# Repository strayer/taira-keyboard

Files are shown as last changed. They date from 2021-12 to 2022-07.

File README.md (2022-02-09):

# Taira Keyboard

## What?

A wireless low-profile split mechanical keyboard with 66 keys inspired by the
ErgoDash and Corne Chocolate. It runs ZMK on two nice!nanos, is fully wireless
via Bluetooth and uses Kailh Choc V1 switches in a 18x19mm grid layout.

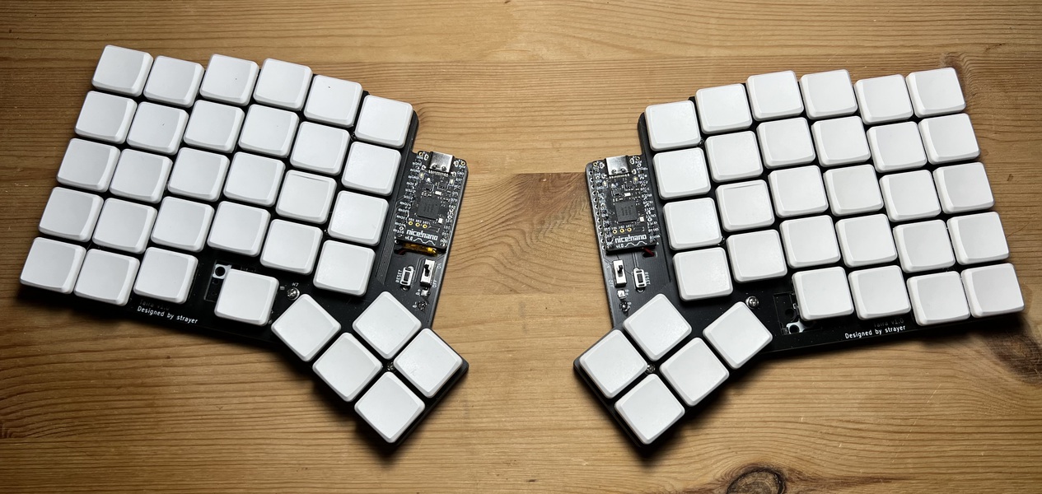
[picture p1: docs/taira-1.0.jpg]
An assembled Taira v1.0


## Why?

I used an ErgoDash with MX switches for over a year multiple hours each day.
Even though I love typing on it, it always felt too bulky and the wires really
started to annoy me - especially when moving between workplaces. At some point I
discovered ZMK and started plans on building a keyboard based on the ErgoDash,
but as low-profile as I could manage.

After investigating which other low-profile keyboards exist in the community, I
quickly realized that the most sophisticated offer seems to be the Corne
Chocolate. This keyboard is heavily based upon the footprints of the Corne
Chocolate, but layed out in a layout very similar to the original ErgoDash.

### ErgoDash comparison

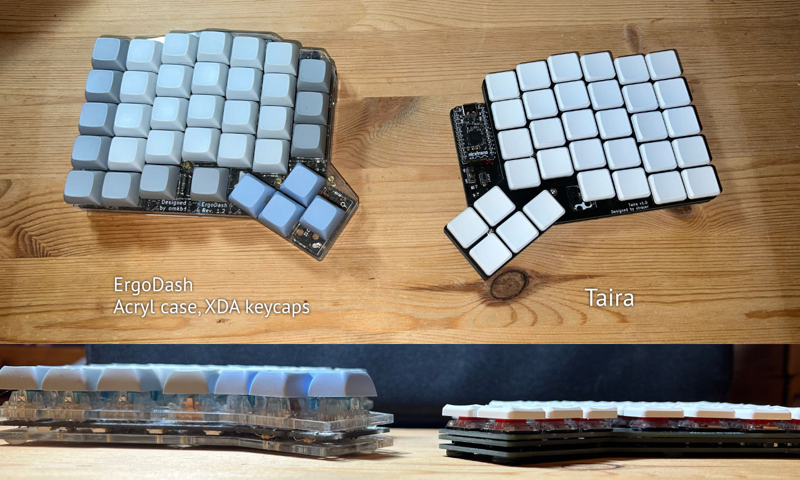
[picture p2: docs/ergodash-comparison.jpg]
An ErgoDash next to a Taira


## Build guide

Follow the [build guide](BUILDGUIDE.md) if you are interested in building your
own Taira.

## Firmware

The ZMK firmware is managed in a separate repository: [strayer/taira-keyboard-zmk-config]

[strayer/taira-keyboard-zmk-config]: https://github.com/strayer/taira-keyboard-zmk-config

## Acknowledgements

Thanks to [@omkbd](https://github.com/omkbd) and
[@foostan](https://github.com/foostan/) for releasing both the ErgoDash and the
Corne Chocolate under the MIT license. Without their work, this keyboard would
not exist.

- https://github.com/omkbd/ErgoDash
- https://github.com/foostan/crkbd/tree/main/corne-chocolate
- an unnamed coworker who helped me _a lot_ while planning and working on the
  keyboard

## Copyright

Copyright 2022 Sven Grunewaldt

License: [MIT](LICENSE)

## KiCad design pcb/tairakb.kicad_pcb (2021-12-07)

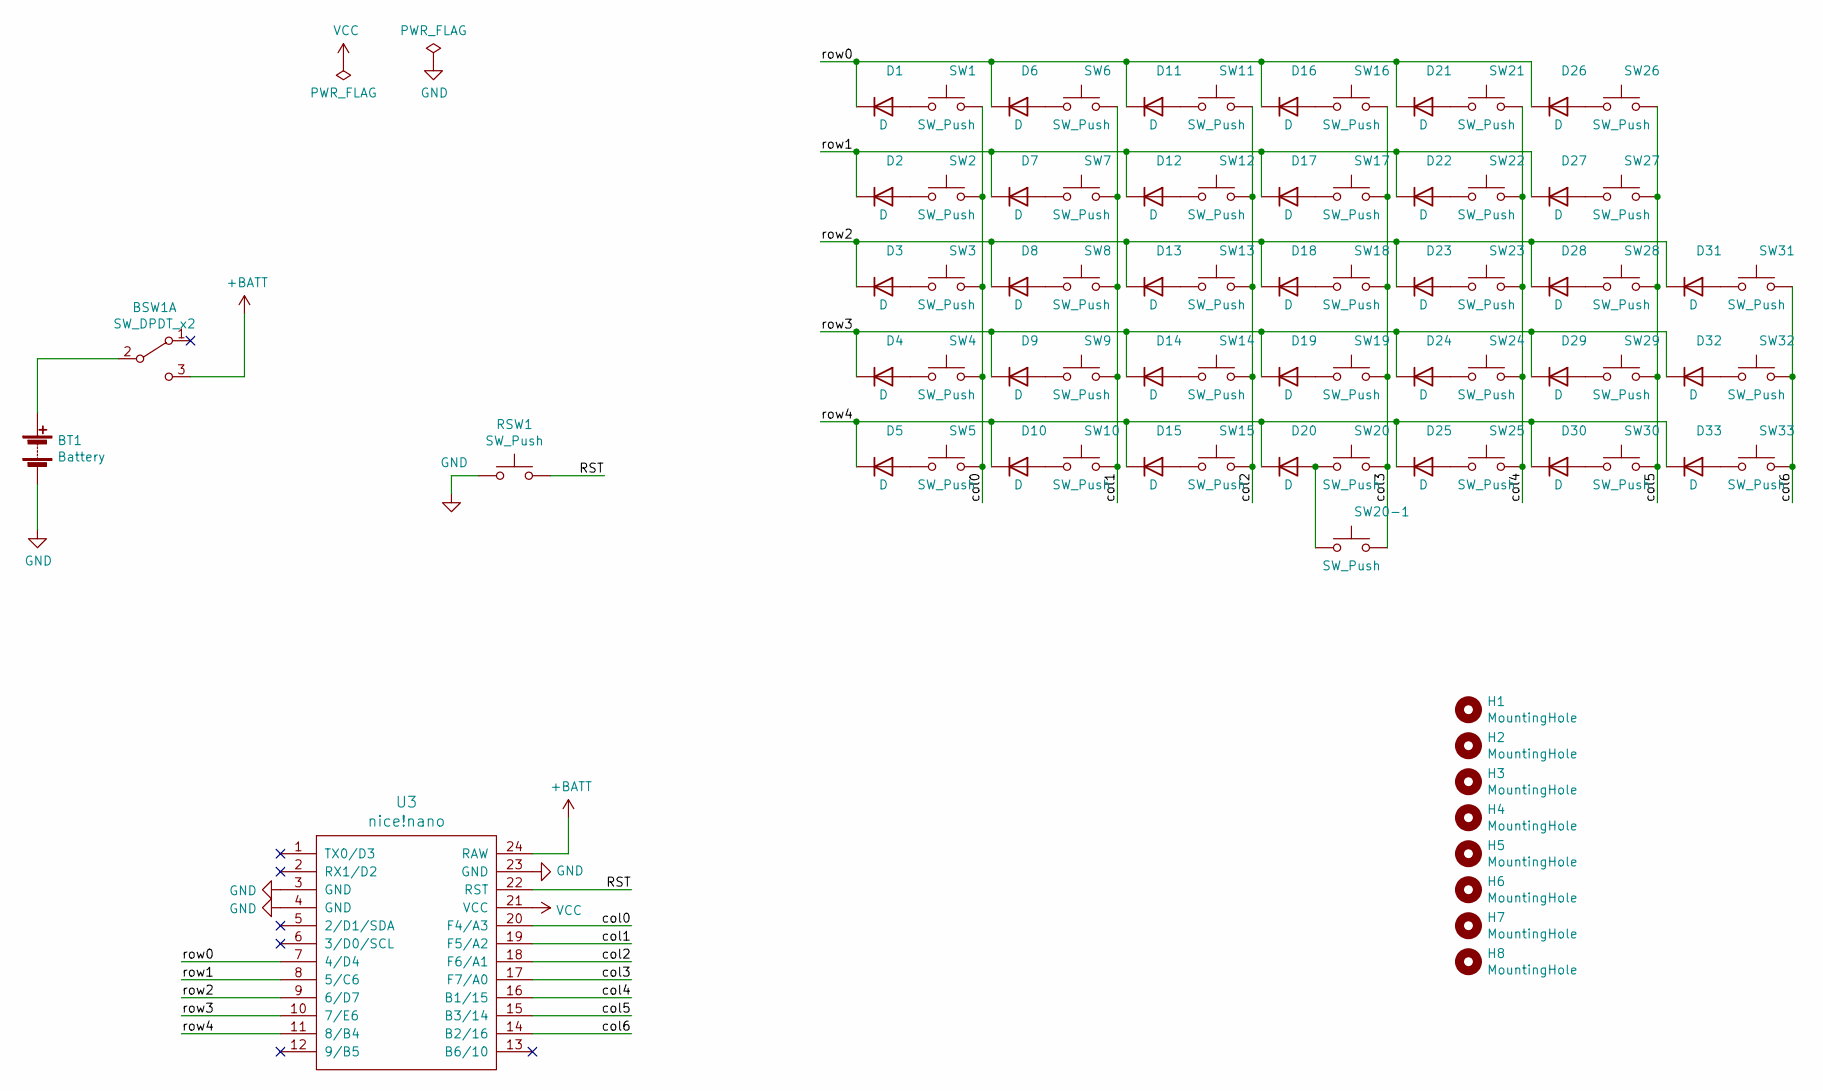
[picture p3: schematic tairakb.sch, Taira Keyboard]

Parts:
BSW1: SW_DPDT_x2; SS-12D00
BT1: Battery; Battery_Wire_Connector
D1, D2, D3, D4, D5, D6, D7, D8, D9, D10, D11, D12, D13, D14, D15, D16, D17, D18, D19, D20, D21, D22, D23, D24, D25, D26, D27, D28, D29, D30, D31, D32, D33: D; D3_SMD
H1, H2, H3, H4, H5, H6, H7, H8: MountingHole; LEGO_HOLE
RSW1: SW_Push; ResetSW
SW1, SW2, SW3, SW4, SW5, SW6, SW7, SW8, SW9, SW10, SW11, SW12, SW13, SW14, SW15, SW16, SW17, SW18, SW19, SW20, SW20-1, SW21, SW22, SW23, SW24, SW25, SW26, SW27, SW28, SW29, SW30, SW31, SW32, SW33: SW_Push; Choc_Hotswap
U3: nice!nano; nicenano

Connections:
+BATT: BSW1.3 (C), U3.24 (RAW)
/RST: RSW1.2, U3.22 (RST)
/col0: SW1.2, SW2.2, SW3.2, SW4.2, SW5.2, U3.20 (F4/A3)
/col1: SW6.2, SW7.2, SW8.2, SW9.2, SW10.2, U3.19 (F5/A2)
/col2: SW11.2, SW12.2, SW13.2, SW14.2, SW15.2, U3.18 (F6/A1)
/col3: SW16.2, SW17.2, SW18.2, SW19.2, SW20.2, SW20-1.2, U3.17 (F7/A0)
/col4: SW21.2, SW22.2, SW23.2, SW24.2, SW25.2, U3.16 (B1/15)
/col5: SW26.2, SW27.2, SW28.2, SW29.2, SW30.2, U3.15 (B3/14)
/col6: SW31.2, SW32.2, SW33.2, U3.14 (B2/16)
/row0: D1.1 (K), D6.1 (K), D11.1 (K), D16.1 (K), D21.1 (K), D26.1 (K), U3.7 (4/D4)
/row1: D2.1 (K), D7.1 (K), D12.1 (K), D17.1 (K), D22.1 (K), D27.1 (K), U3.8 (5/C6)
/row2: D3.1 (K), D8.1 (K), D13.1 (K), D18.1 (K), D23.1 (K), D28.1 (K), D31.1 (K), U3.9 (6/D7)
/row3: D4.1 (K), D9.1 (K), D14.1 (K), D19.1 (K), D24.1 (K), D29.1 (K), D32.1 (K), U3.10 (7/E6)
/row4: D5.1 (K), D10.1 (K), D15.1 (K), D20.1 (K), D25.1 (K), D30.1 (K), D33.1 (K), U3.11 (8/B4)
GND: BT1.2 (-), RSW1.1, U3.3 (GND), U3.4 (GND), U3.23 (GND)
unnamed: BSW1.2 (B), BT1.1 (+)
unnamed: D1.2 (A), SW1.1
unnamed: D2.2 (A), SW2.1
unnamed: D3.2 (A), SW3.1
unnamed: D4.2 (A), SW4.1
unnamed: D5.2 (A), SW5.1
unnamed: D6.2 (A), SW6.1
unnamed: D7.2 (A), SW7.1
unnamed: D8.2 (A), SW8.1
unnamed: D9.2 (A), SW9.1
unnamed: D10.2 (A), SW10.1
unnamed: D11.2 (A), SW11.1
unnamed: D12.2 (A), SW12.1
unnamed: D13.2 (A), SW13.1
unnamed: D14.2 (A), SW14.1
unnamed: D15.2 (A), SW15.1
unnamed: D16.2 (A), SW16.1
unnamed: D17.2 (A), SW17.1
unnamed: D18.2 (A), SW18.1
unnamed: D19.2 (A), SW19.1
unnamed: D20.2 (A), SW20.1, SW20-1.1
unnamed: D21.2 (A), SW21.1
unnamed: D22.2 (A), SW22.1
unnamed: D23.2 (A), SW23.1
unnamed: D24.2 (A), SW24.1
unnamed: D25.2 (A), SW25.1
unnamed: D26.2 (A), SW26.1
unnamed: D27.2 (A), SW27.1
unnamed: D28.2 (A), SW28.1
unnamed: D29.2 (A), SW29.1
unnamed: D30.2 (A), SW30.1
unnamed: D31.2 (A), SW31.1
unnamed: D32.2 (A), SW32.1
unnamed: D33.2 (A), SW33.1
VCC: U3.21 (VCC)

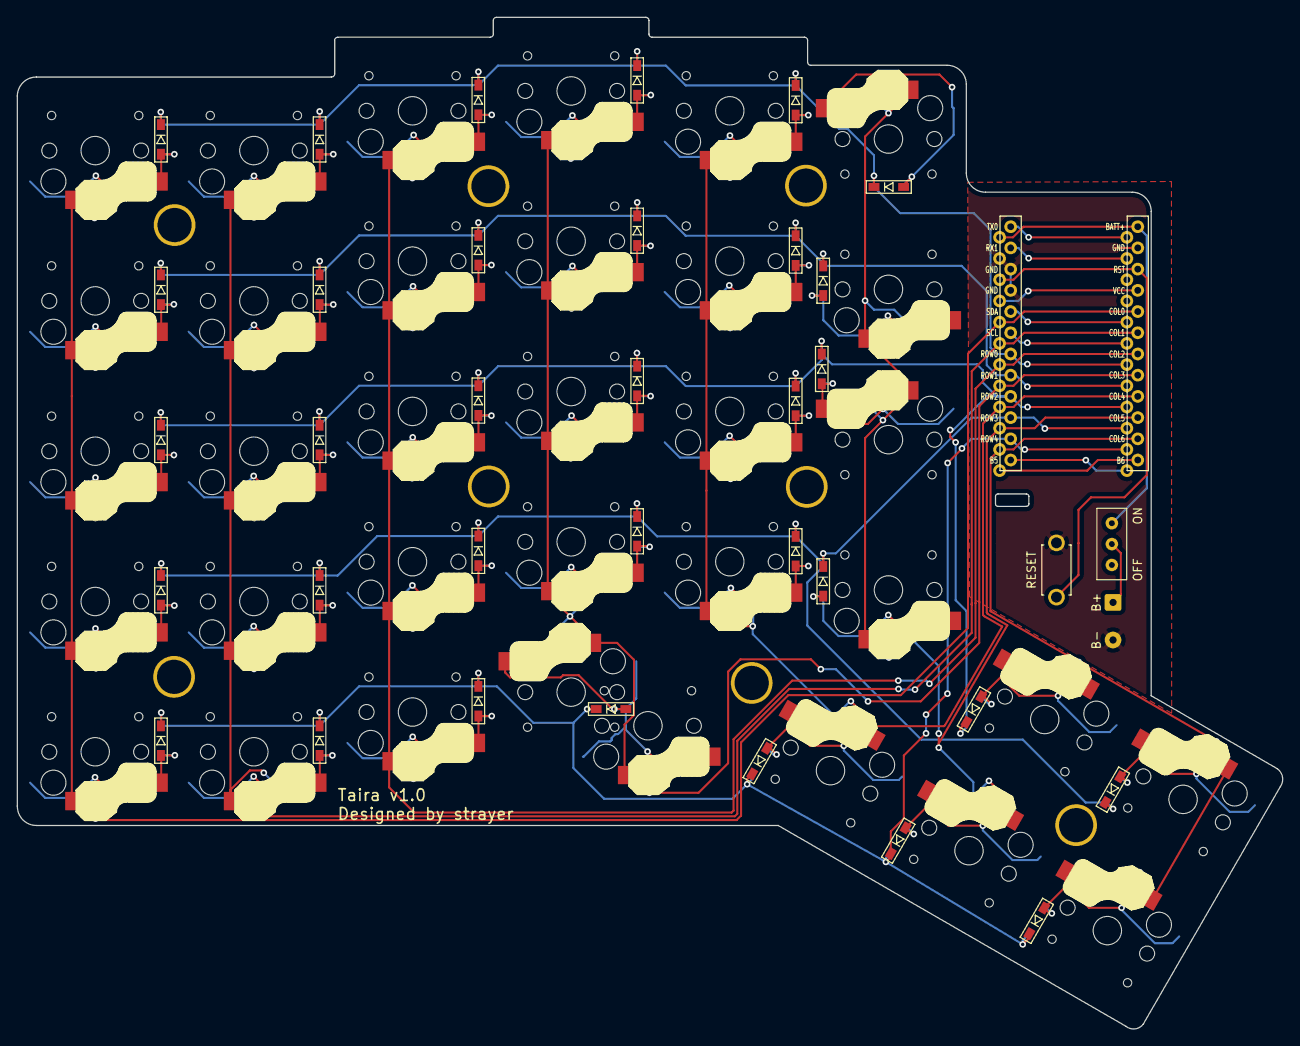
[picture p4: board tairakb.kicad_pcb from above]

Board: 2 copper layers, 151.5 x 121.2 mm, 79 parts (0 on the bottom side), 49 nets.

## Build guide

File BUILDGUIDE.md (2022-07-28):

# Build Guide

## Parts

The following parts list has links to various shops. Please don't see this as an
endorsement for the shops, its just where I ended up ordering the things I used
to help you find the correct parts. I found it quite difficult to find screws
and spacers that will fit the tight build, for example.

| Name | Amount | Remarks | Part |
| :--- | :----- | :--- | :--- |
| PCB | 2 | | |
| Top plate | 2 | | |
| Bottom plate | 2 | | |
| nice!nano | 2 | | [nice!nano on nicekeyboards.com] |
| 301230 LiPo battery | 2 | | |
| Mill-Max Series 315 header | 4 | | [headers on keycapsss.com] |
| Mill-Max Series 315 pin | 48 | | [pins on keycapsss.com] |
| Tactile switch | 2 | | [TS-1136-4.3] |
| Power switch | 2 | | [SS12D00] |
| Diode | 66 | | SOD-123FL |
| Kailh Choc Hotswap Socket  | 66 | | [Choc Type Hot Swap Socket] |
| Key switch | 66 | | PG1350, NOT Choc V2! |
| Keycaps | 66 | The Taira is NOT compatible with keycaps intended for 19x19mm switch spacing! | [MBK Choc Low Profile Blank Keycaps] |
| Spacer M2 4mm | 16 | | [brass round standoff, m2x4] |
| Screw M2 3mm | 32 | | [m2x3 screw] |
| Cushion rubber feet | 28 | I had to stack two 1mm cushion rubbers to be higher than the screws, so 7x2x2 | [adhesive rubber feet 1mm] |
| USB-C cable | 1-2 | At least one for charging the battery, two during assembly | |

[nice!nano on nicekeyboards.com]: https://nicekeyboards.com/nice-nano/
[headers on keycapsss.com]:
  https://keycapsss.com/keyboard-parts/parts/100/single-row-socket-headers-or-pins-mill-max-series-315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
[pins on keycapsss.com]:
  https://keycapsss.com/keyboard-parts/parts/100/single-row-socket-headers-or-pins-mill-max-series-315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
[ss12d00]: https://aliexpress.com/item/4000770828576.html
[ts-1136-4.3]: https://aliexpress.com/item/1068908059.html
[choc type hot swap socket]:
  https://www.kailhswitch.com/mechanical-keyboard-switches/box-switches/choc-type-hot-swap-socket.html
[mbk choc low profile blank keycaps]:
  https://keycapsss.com/keyboard-parts/keycaps/169/mbk-choc-low-profile-blank-keycaps?number=KC10130_1U-WH
[brass round standoff, m2x4]: https://aliexpress.com/item/32968906213.html
[m2x3 screw]: https://www.amazon.de/gp/product/B00W96Z5RQ
[adhesive rubber feet 1mm]: https://www.amazon.de/gp/product/B06WRQ471S

## Printing the PCBs and plates

Download the gerber files from the [latest release](https://github.com/strayer/taira-keyboard/releases/latest).

These were exported from KiCad to be printed by JLC PCB. Check your PCB fab for
their requirements and maybe export new gerber files with KiCad yourself.

## Firmware preparation

Download the latest firmware from [strayer/taira-keyboard-zmk-config], you will
need it later to test the nice!nanos during the build process.

[strayer/taira-keyboard-zmk-config]:
  https://github.com/strayer/taira-keyboard-zmk-config

## Building

Decide which of the PCBs should be the left and right side. You will have to
solder some things to the back side and front side, so find a way to keep track
on which side you are currently working.

### Diodes

First, solder the diodes to the PCB.

The diodes **MUST** be attached to the bottom side of the PCB! Not all diodes
are directed in the same way, so keep an eye on the arrow markings on the PCB
silkscreen to orient the diodes in the right direction.

The orientation of the diode is as follows: Attach the chip component so that
the "|||" mark on the diode is facing the "|" of the diode mark "|◁" on the PCB.

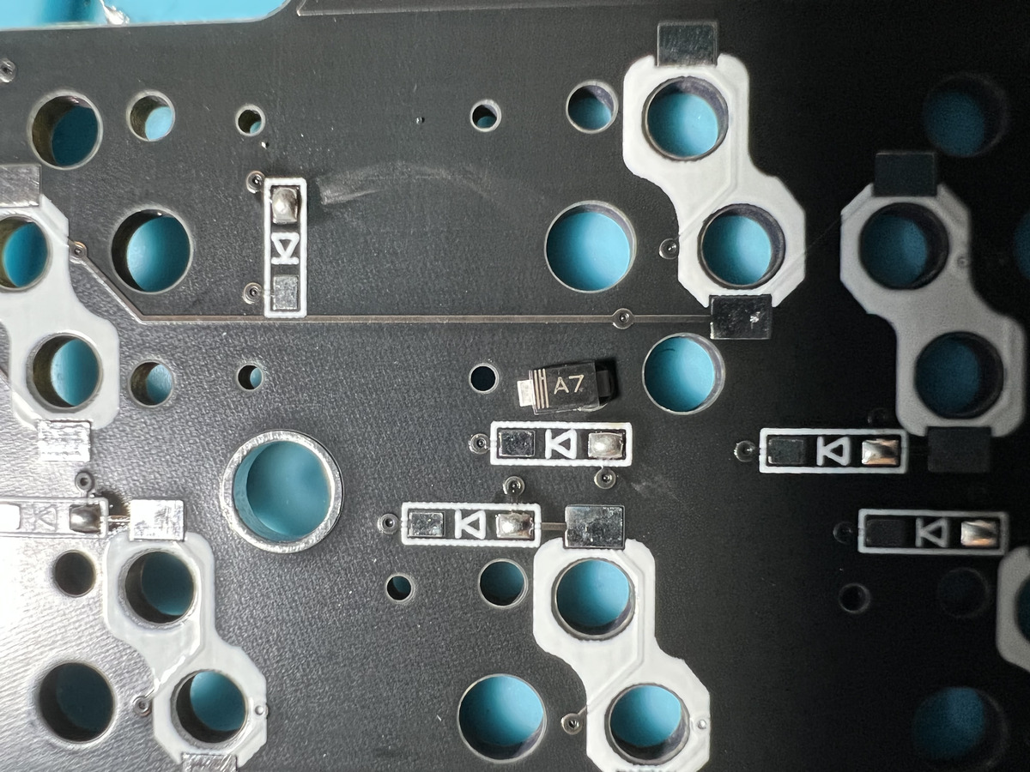
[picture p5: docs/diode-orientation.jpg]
Diode orientation


Prepare the PCB by putting solder on the right pad of all diode spots. Next,
solder the diodes by melting the solder on the PCB while holding them on the
pad.

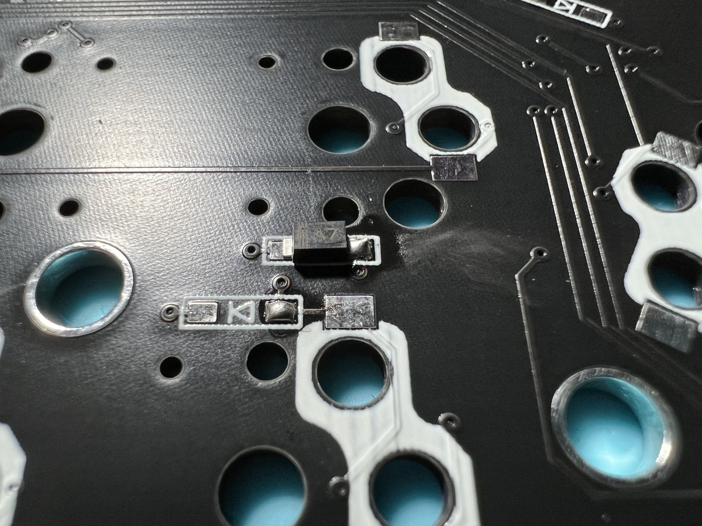
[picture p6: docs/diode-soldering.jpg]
A diode soldered on the right side


Continue with soldering the other side of the diodes to the PCB.

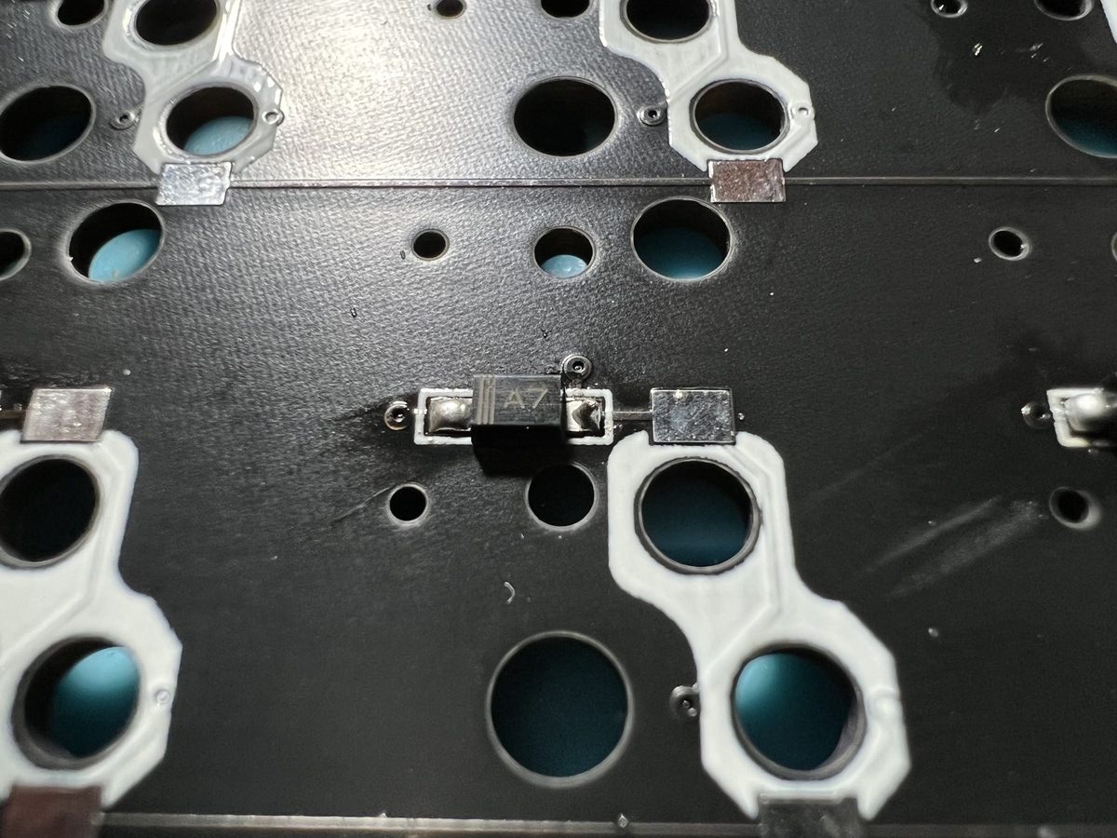
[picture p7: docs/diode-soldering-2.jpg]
A diode soldered on both sides


### Power and reset switch

Solder the power switch and reset switch to the **FRONT** of the PCB. The
orientation of both components doesn't matter.

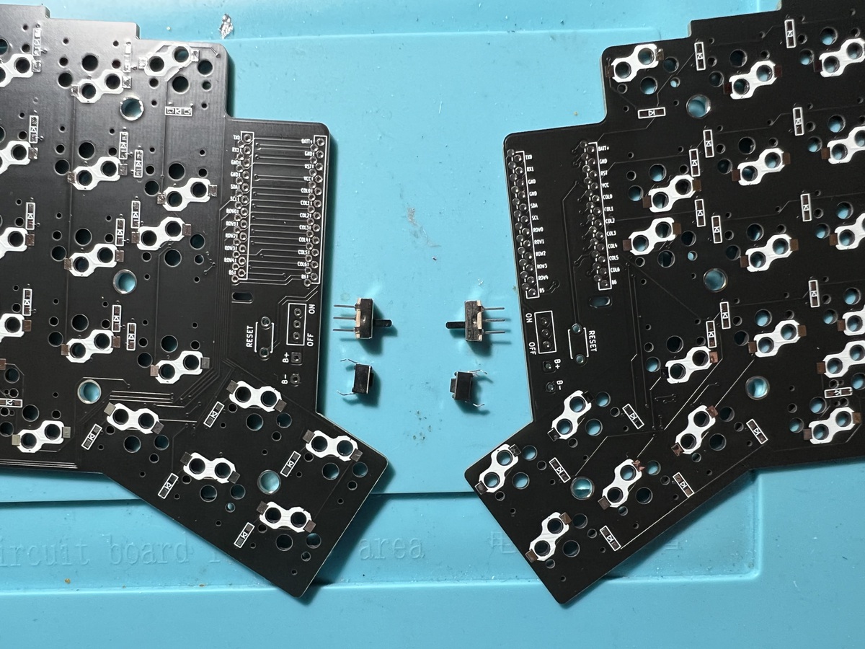
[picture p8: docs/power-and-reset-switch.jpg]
The power and reset switches


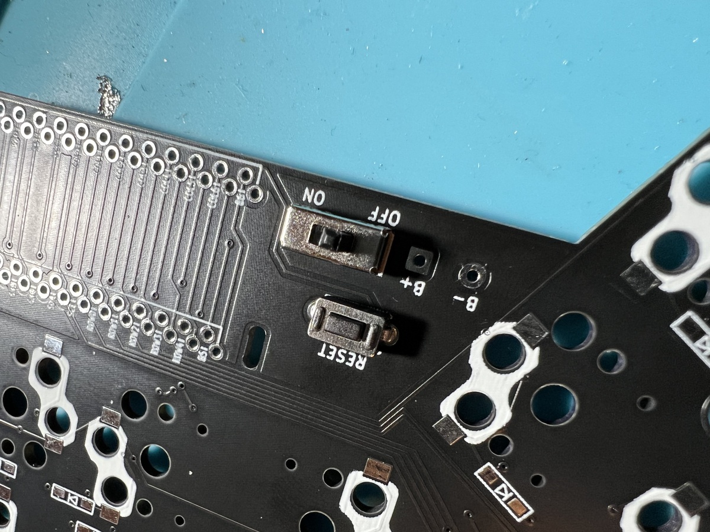
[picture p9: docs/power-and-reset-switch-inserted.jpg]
Power and reset switch inserted into the respective sockets


Clip the legs to avoid conflicts with the bottom plate.

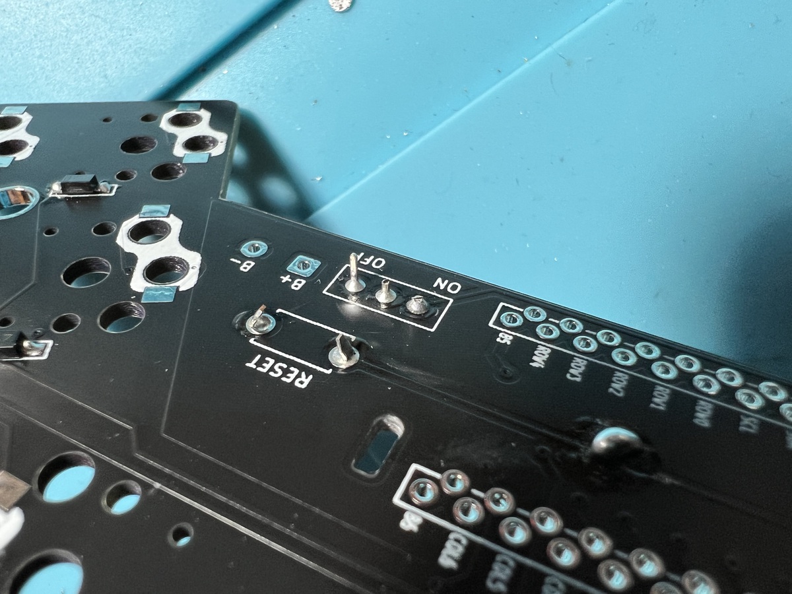
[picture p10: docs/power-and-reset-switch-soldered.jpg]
Soldered and clipped power and reset switch


### nice!nano

Solder the sockets for the nice!nano to the **FRONT** of the PCB. The correct
holes for the left and right PCB are marked with a white frame.

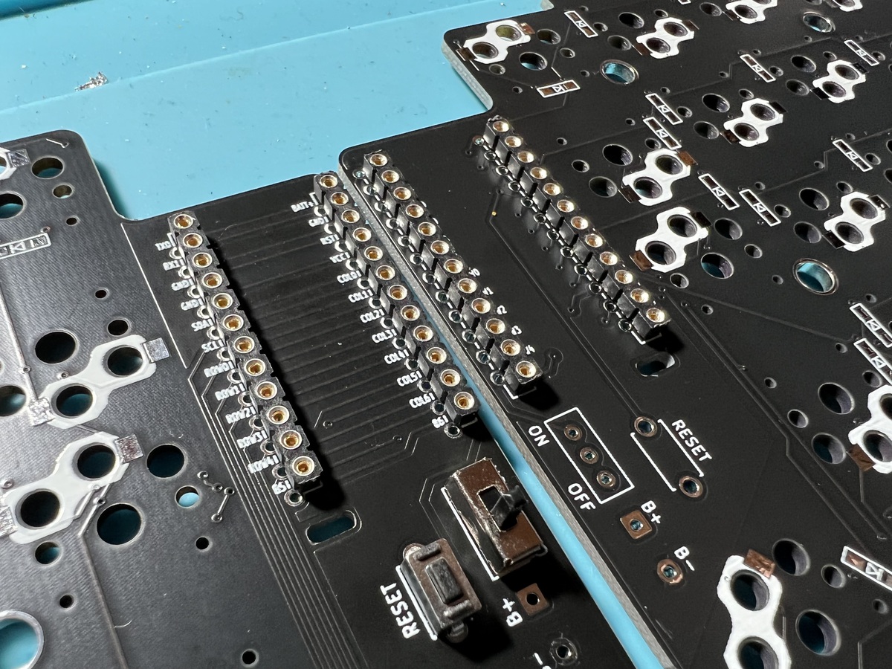
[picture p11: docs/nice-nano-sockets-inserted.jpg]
nice!nano sockets inserted


**IMPORTANT**: Check that you didn't short the pins of the nice!nano by
accident! Due to the flippable PCB design it is easy to make a solder bridge
between the front and bottom socket hole and create shorts.

Solder the MillMax pin legs to the nice!nano. **IMPORTANT**: The side of the
nice!nano with the silkscreen markings, components and LEDs must be on top!
There are various guides on how to do this, one is linked in the documentation
of the nice!nano itself:
[nicekeyboards.com: Socketing the nice!nano](https://nicekeyboards.com/docs/nice-nano/getting-started#socketing-the-nicenano)

I did this by putting kapton tape over the two socket rows, inserting the
millmax pins or diode legs in each hole, putting the nice!nano on top of it and
soldering the pins in place.

Note: I recommend using MillMax pins instead of leftover diode legs as described
in some guides. I tried both and the MillMax pins are _much_ more sturdy. It is
**VERY** easy to bend the pins and rip a nice!nano with diode legs out of the
sockets just by picking up the board while it is charging via USB-C.

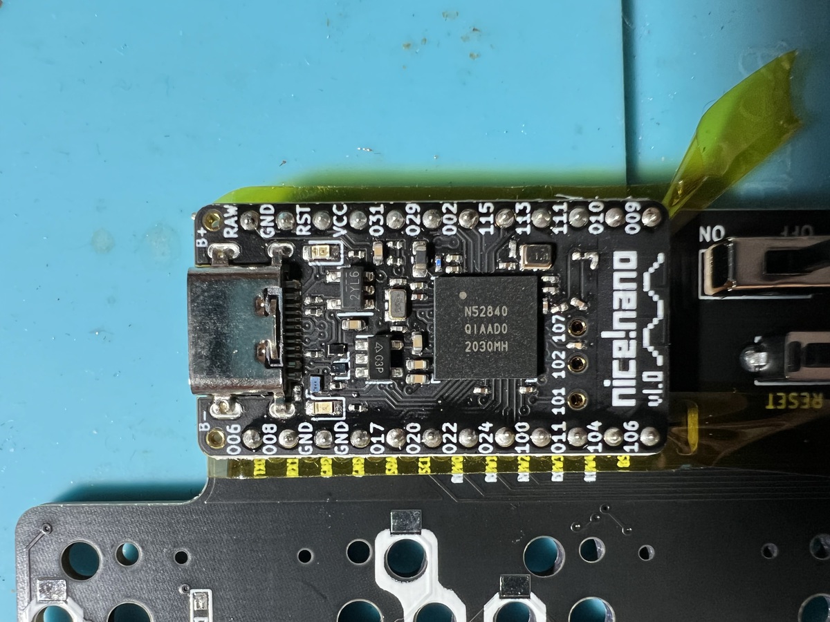
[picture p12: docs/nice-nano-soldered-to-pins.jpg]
nice!nano soldered to pins


### Operation check

Put the nice!nano in the sockets and attach it to your computer with a USB-C
cable. Flash the left and right firmware as described in the ZMK documentation
to the respective nice!nanos. Afterwards only the left side needs to be
connected to the computer, the right side will connect to the left side via
Bluetooth as long as it has power through USB-C. If everything is working
correctly you should be able to simulate key presses by shorting the hotswap
sockets solder pads. Also try pressing the reset buttons to check if the
nice!nanos reset as expected (the blue LED should flash).

### Kailh Hotswap Sockets

Solder the Kailh Hotswap Sockets the same way you did the diodes, also on the
**BACK** of the PCB. The correct spots are again marked with white silkscreen.
Put solder on the right pad of all hotswap socket spots, put the socket into
position and hold it down with tweezers while melting the solder through the
metal part of the socket. Afterwards heat up the left metal part of the socket
and solder it on the pad.

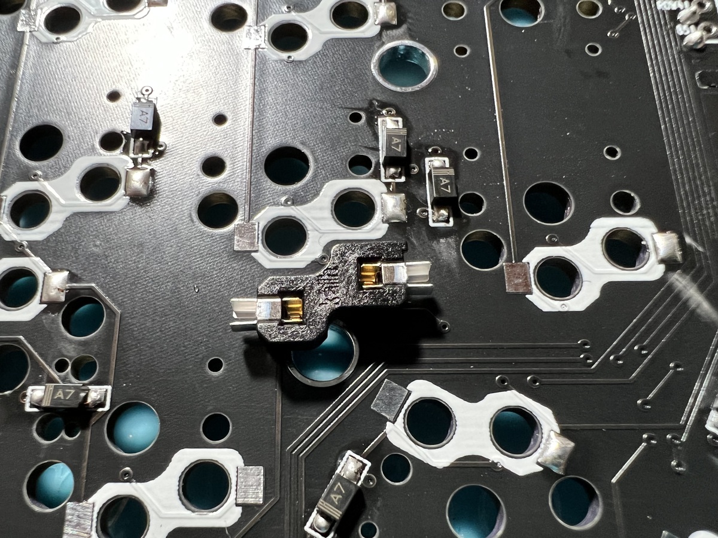
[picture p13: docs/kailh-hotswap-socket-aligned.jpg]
Kailh hotswap socket aligned to PCB


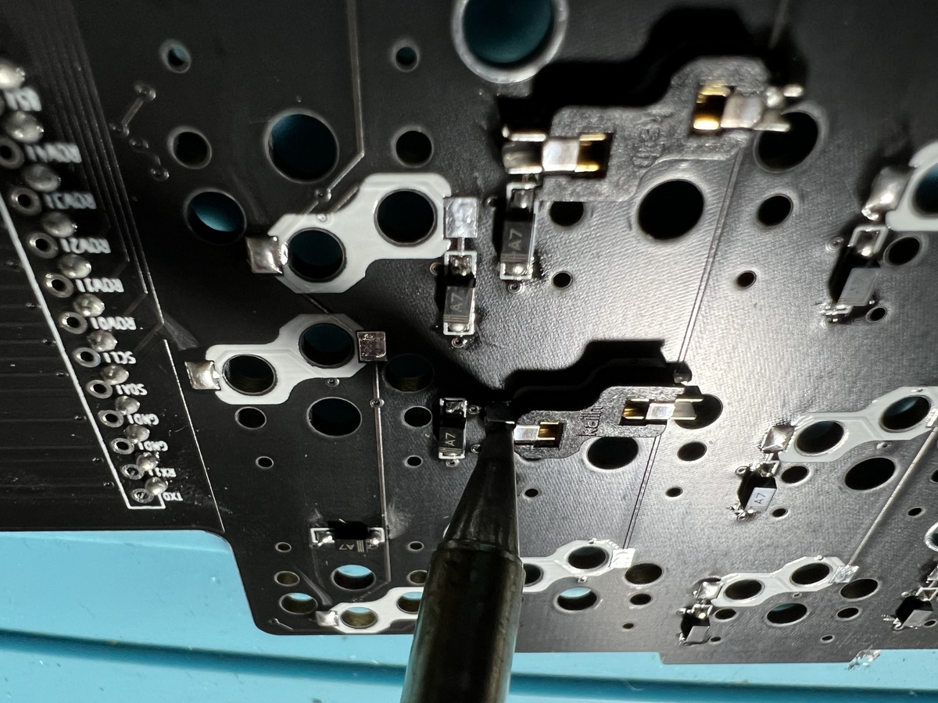
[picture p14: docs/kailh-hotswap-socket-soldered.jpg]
Kailh hotswap socket soldered on one side


The fourth socket in the bottom row can be put in two different positions. You
can either have four switches next to each other to have HJKL-like arrow keys or
have the switch a bit further to the center to make it easier to reach it with
your thumb. You can also solder hotswap sockets to both positions if you want to
be able to switch positions later. The default keymap is intended to be used
with the thumb on the left side (mapped to Alt) and as arrow keys on the right
side (mapped to ←↓↑→).

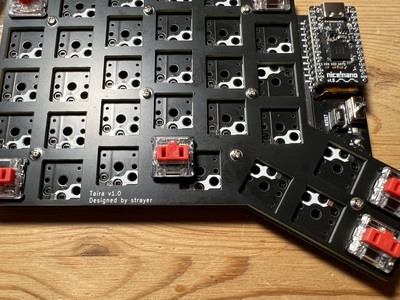
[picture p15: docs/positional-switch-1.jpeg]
Switch in position 1

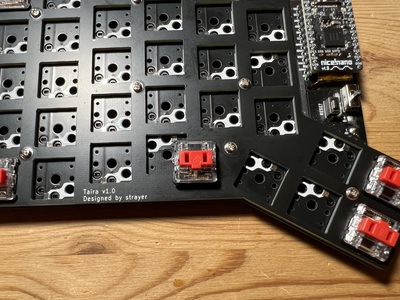
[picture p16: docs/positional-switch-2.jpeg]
Switch in position 2


### Batteries

First remove the nice!nano from the socket and make sure the power switch is set
to OFF. Place the battery between the sockets for the nice!nano. Guide the wires
through the hole in the PCB to the back side and solder them into the B+ and B-
holes there. Measure the voltage if you are unsure which wire is positive and
negative. Be extra careful to NOT short the battery terminals/wires! I opted to
secure the wires and soldering spots with kapton tape. I also put kapton tape on
the back of the nice!nano to avoid it touching the battery directly, although
this is probably unnecessary.

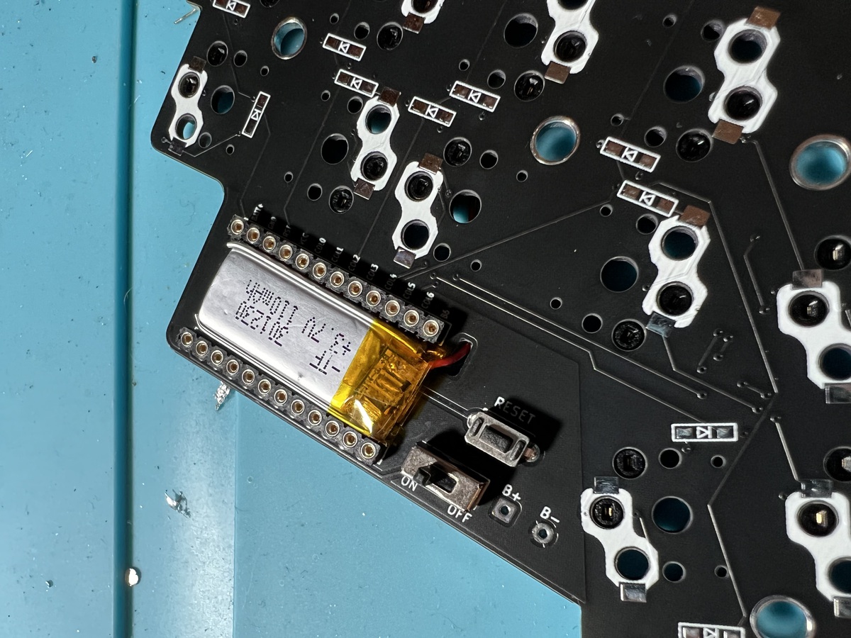
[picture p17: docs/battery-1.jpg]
Battery aligned between the nice!nano sockets

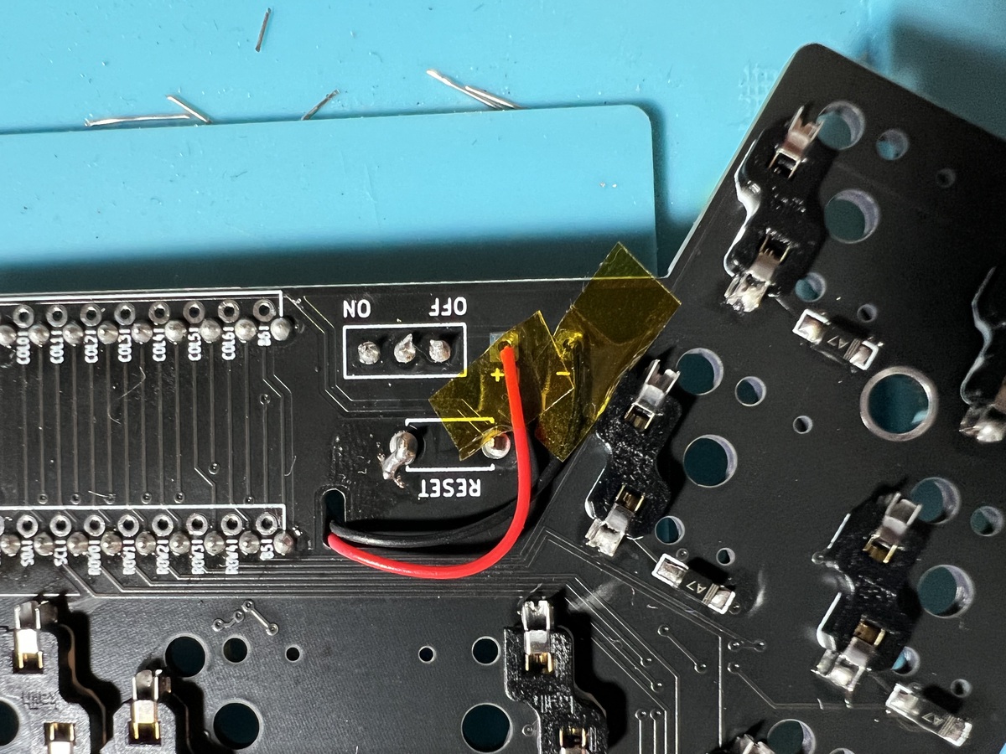
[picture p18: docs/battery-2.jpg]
Battery wires soldered to PCB


Put the nice!nano back into the socket and flip the power switch. Make sure the
LEDs on the nice!nano light up to test the connection. (Note: This may not work
when the battery is discharged)

A new Bluetooth device named "Taira" should appear on your device after turning
on the power switch. Try to connect to it and short the hotswap sockets again to
test, ideally with both sides turned on.

### Top and bottom plates

Take a top plate and put a 3mm screw from the top through the hole and screw on
a spacer, repeat this for every hole. Guide the spacers through the assembled
PCB, place the bottom plate on it and secure it with a 3mm screw in each hole.
The distance between the PCB and the top plate should be so that an inserted
switch is supported by the top plate while still touching the PCB.

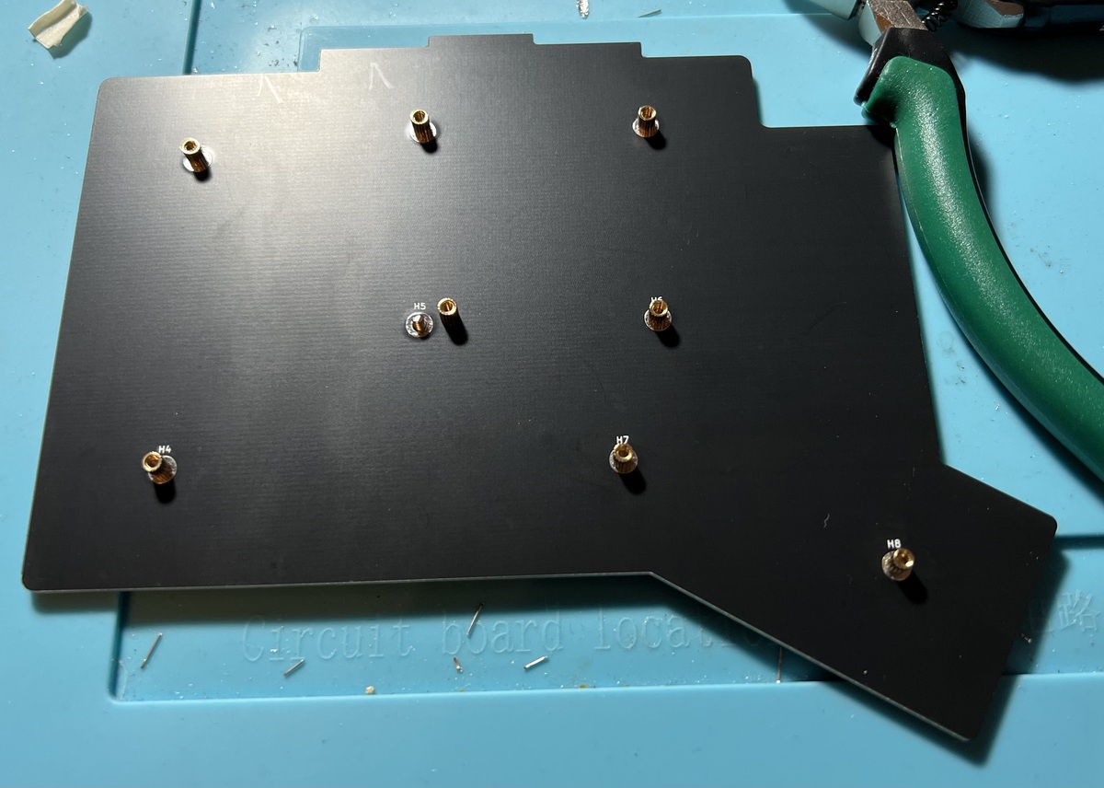
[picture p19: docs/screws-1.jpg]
Spacers secured to top plate

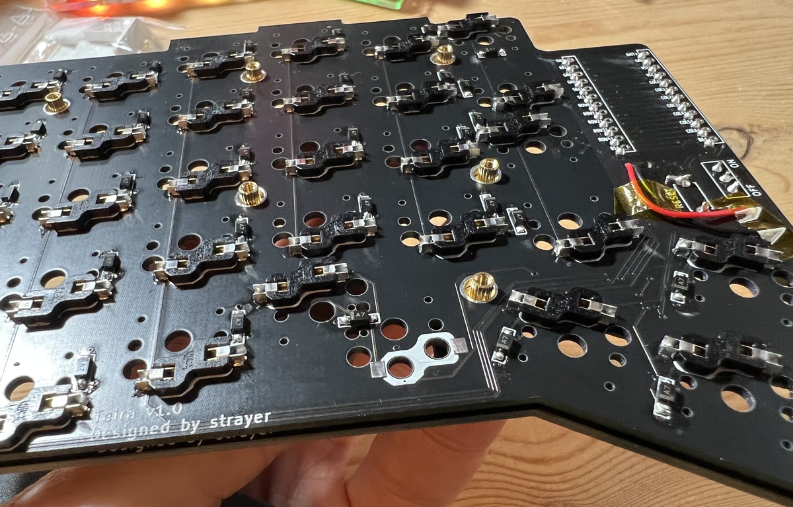
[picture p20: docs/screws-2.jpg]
Top plate guided through PCB

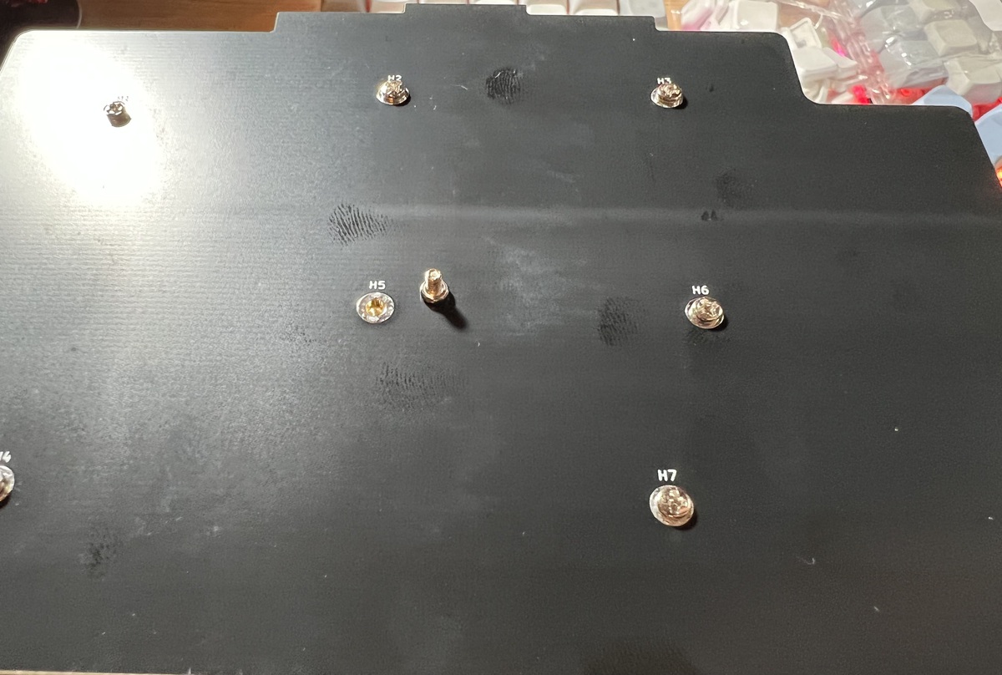
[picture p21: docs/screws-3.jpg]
Bottom plate secured to spacers


Add some rubber pads / feet to the bottom plate to reduce noise while typing and
avoid sliding.

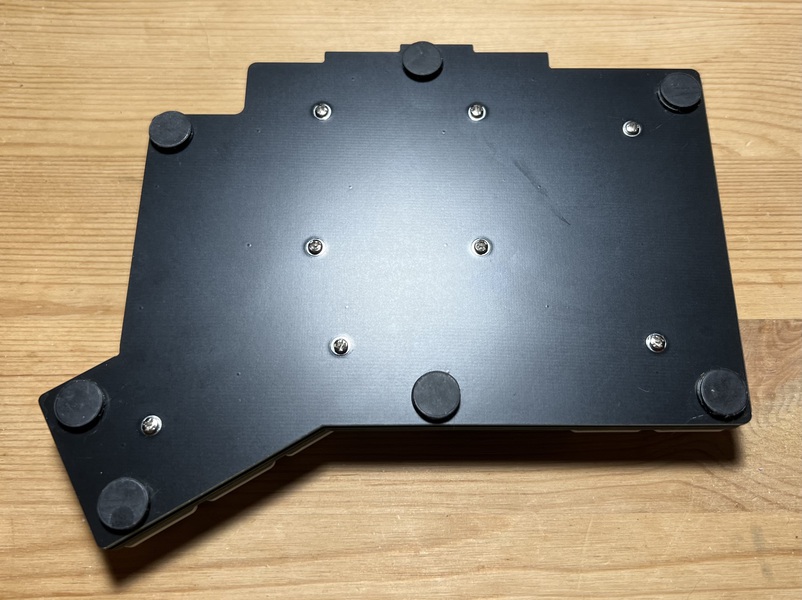
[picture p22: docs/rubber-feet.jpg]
Bottom plate with rubber feet


### Switches

Gently insert each Kailh Choc switch into the hotswap sockets. It will require
some force, but keep in mind that it _is_ possible to lift off the socket pad if
using too much force or changing switches too often.

If required, push the top plate up to the switch support with a screwdriver.

Finally, attach the keycaps.

### Conclusion

Congratulations! You successfully built a Taira keyboard!

I'd love to get feedback on the build process and the keyboard itself - feel
free to e-mail me at [strayer@olle-orks.org](mailto:strayer@olle-orks.org) or
[start a discussion on Github](https://github.com/strayer/taira-keyboard/discussions)!

A finished Taira v1.0

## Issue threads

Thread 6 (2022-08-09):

Use without the hotswap plates?

rzfzr, 2022-08-09:
Firstly, thanks for sharing.
I already have the switches, no interest in using the plates, I notice from the pictures that it has unpadded holes, are those choc compatible? It's just a matter of 'tinning' the pads with KiCad ? or it's lacking the internal wiring for it? I'm a full noob in this custom pcb realm.
Thanks again

strayer, 2022-08-10:
Hey @rzfzr. I'm assuming you are talking about the Kailh hotswap sockets? If you are going that route I'd recommend replacing the whole footprint in Kicad with one that is already prepared for directly soldering the switches. The traces will need to be retraced too, as they are then hanging in the air. Although that shouldn't be that difficult since the hotswap socket pads are pretty much in the same area as the switch contact legs are.

rzfzr, 2022-08-10:
Cool,
If I end up going that route I'll make sure to link it.
the hot swap sockets are cheap enough that I might just go with that instead though.
Thanks

Closed 2022-08-10.

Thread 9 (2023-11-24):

Column Stopped Working

Bwata, 2023-11-24:
First, thanks for this project, I have enjoyed my keyboard for many months now.

Second, Just recently a column stopped working. I tried re-soldering what I think were the connections to the board and that did nothing. I am here asking for advice on how to trouble shoot or fix. It is the second column (going left to right) on the left side.

madushan1000, 2023-12-15:
I had a similar issue, It was a bad solder joint in my controller(nrfmicro). test if all the gpio pins work.

strayer, 2023-12-15:
Hey! Sorry for not responding. Funnily enough I had a similar issue with the number row not working on my second half for a while. In my case it was also a bad solder joint that was fixed by resoldering the headers for the nice!nano. Before that I had to wiggle the nice!nano a bit to "reconnect" the solder joints.

Since you already tried resoldering: You can also test this by shorting the relevant GPIO pins on the nice!nano with wires, pliers or something else conducting. Just be extra sure that you short the correct GPIO pins and don't fry the nice!nanos! Been there… 🙈 Check the schematics which GPIO pins would be shorted by the keyboard matrix for the column you are experiencing issues with - when shorting the GPIOs manually the system the keyboard is paired to should receive the key press. If not I'd assume something might be wrong with the nice!nano.

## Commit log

2021-12-07 Add first draft of Taira Keyboard
    [tairakb.kicad_pcb, tairakb.sch]
2021-12-07 Remove unnecessary PWR_FLAG
    [tairakb.sch]
2021-12-07 Add traces routed by hand
    Previously the diodes were connected from the columns to the switches.
    Both the ErgoDash and the Corne have them behind the switches connected
    to the rows. Since I positioned the diodes on the PCB like they are in
    the ErgoDash and Corne, the routing was much more difficult than intended.
    This moves the diodes behind the switches and also moves them around a
    bit on the PCB. This allowed me to hand route all traces easily, so this
    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
    [tairakb.kicad_pcb, tairakb.sch]
2021-12-07 Add revision 1.0
    Pretty much everything changed. A lot of things were fixed, plates were
    added and the spacing between the keys is now 1mm (there was no spacing
    before).
    [taira-bottom-plate-B_Cu.gbl, taira-bottom-plate-B_Mask.gbs, taira-bottom-plate-B_Paste.gbp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]
2021-12-07 Fix incorrect switch cutout on top plate
    [taira-bottom-plate-B_Cu.gbl, taira-bottom-plate-B_Mask.gbs, taira-bottom-plate-B_Paste.gbp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]
2022-07-28 Update BUILDGUIDE.md
    Part numbers for switches were swapped.

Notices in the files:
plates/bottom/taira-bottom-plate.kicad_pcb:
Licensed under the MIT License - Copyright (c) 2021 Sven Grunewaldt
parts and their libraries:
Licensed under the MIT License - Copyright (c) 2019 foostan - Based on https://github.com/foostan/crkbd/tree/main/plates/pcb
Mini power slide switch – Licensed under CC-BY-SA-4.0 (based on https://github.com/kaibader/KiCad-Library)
